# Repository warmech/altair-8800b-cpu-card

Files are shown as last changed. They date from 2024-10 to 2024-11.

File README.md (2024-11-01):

# Altair 8800B CPU Card
This is a reproduction of the MITS Altair 8800B CPU card, with some cleanup to trace routing and pad placement. While there are reproductions of the 8800's CPU card available, the 8800B's CPU card has not (to date) been reproduced. You may be wondering why this version of the Altair's CPU card exists and the original 8800 card is not useable; this is because the architecture of the 8800 and 8800B differ ever so slightly, making each computer's CPU card incompatible with the other without making some hardware changes.

This version of the card incorporates all of the pertinent hardware design of the original 8800B card, but leaves out all of the unnecessary and/or ancillary traces and pads that were placed for potential future development. Orphaned pads, jumpers, and vias have been removed and only two unlabeled jumpers remain in the vicinity of IC "T" near the bottom-left side of the PCB. The goal of this project was not to recreate the card in a 1:1 fashion, as the original PCB was replete with elements that served no discernably meaningful purpose. Instead, this revision offers a nice, clean, annotated PCB for those whose 8800Bs are either missing a CPU card (as mine was) or whose CPU cards are damaged beyond repair.

This design is presently untested and I am awaiting a set to be fabricated. Once I have tested this card in my 8800B, I will update this disclaimer to indicate as much.

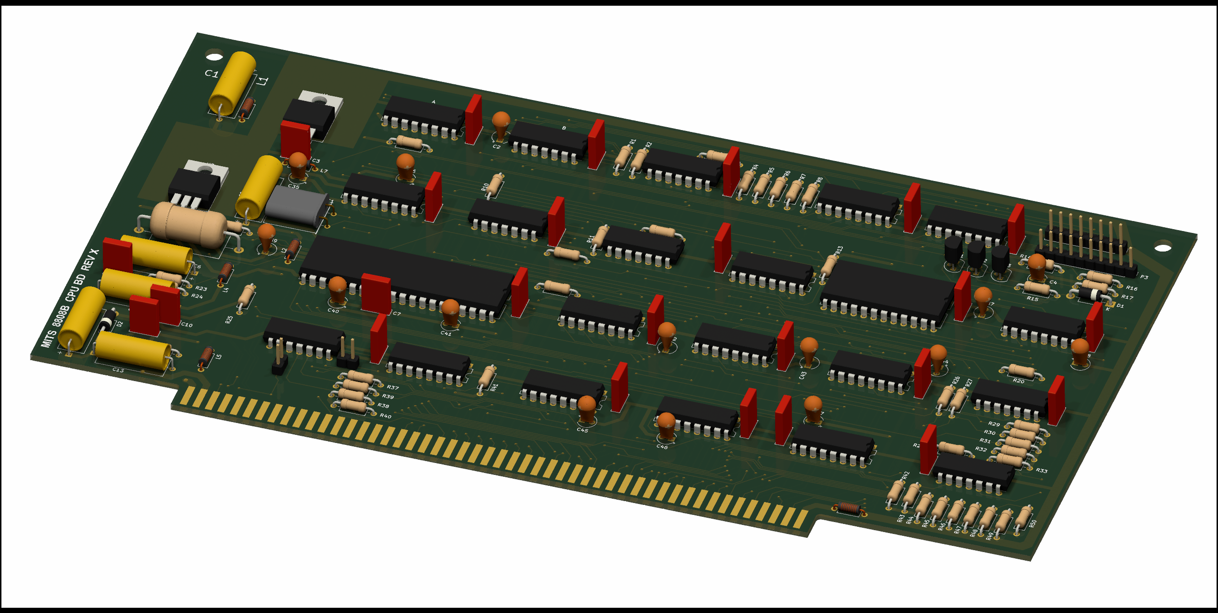
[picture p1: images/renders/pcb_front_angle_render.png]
Altair 8800B CPU Front


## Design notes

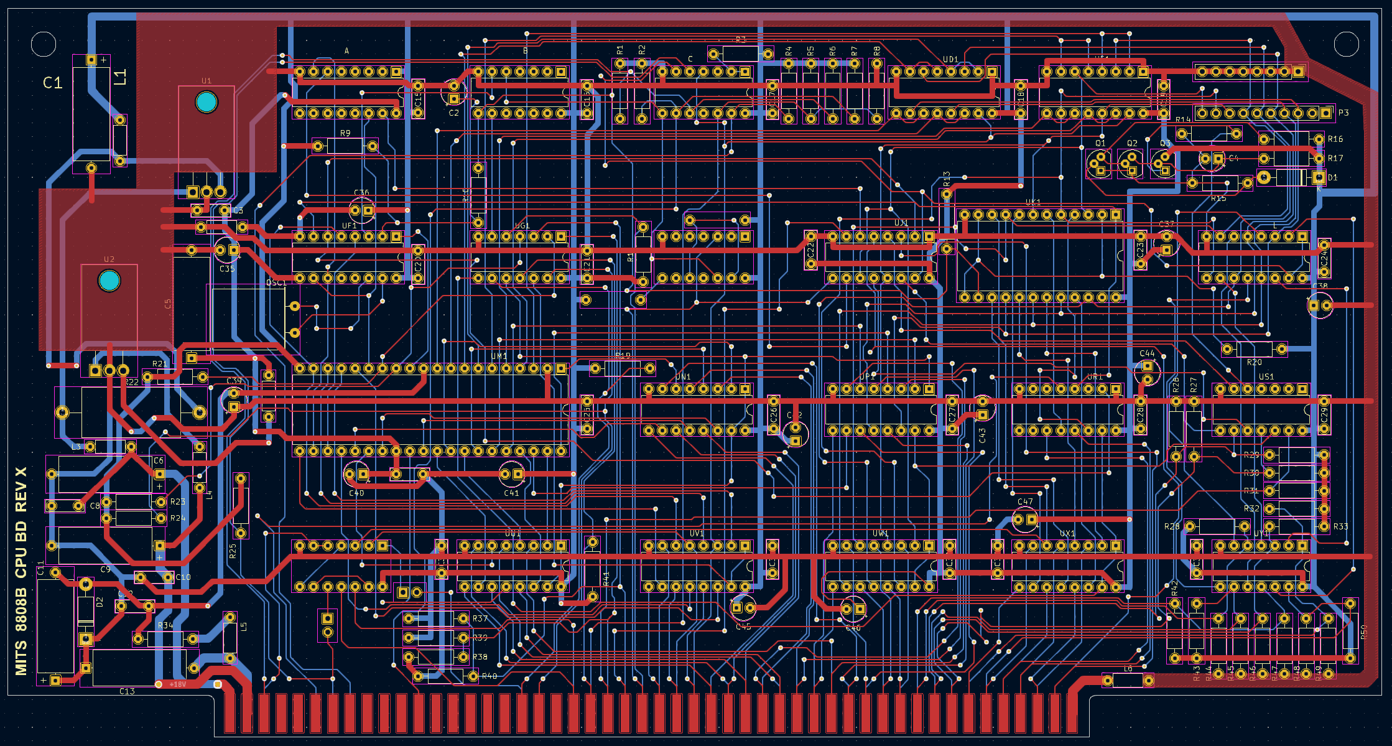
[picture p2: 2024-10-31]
images/renders/pcb_cad_view.png

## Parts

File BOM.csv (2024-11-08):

Source: | C:\Users\wtooker\GitHub\altair-8800b-cpu-card\cad\altair-8800b-cpu-card.kicad_sch
Date: | 11/8/2024 1:40:58 PM
Tool: | Eeschema 7.0.8
Generator: | C:\Program Files\KiCad\7.0\bin\scripting\plugins/bom_csv_grouped_by_value.py
Component Count: | 136
Collated Components:
Item | Qty | Reference(s) | Value | LibPart | Footprint | Datasheet | DNP
1 | 4 | C1, C5, C6, C11 | 33uF 16V | Device:C_Polarized_US | Capacitor_THT_Custom:C_Axial_L17.0mm_D6.5mm_P20.00mm_Horizontal | ~
2 | 1 | C2 | 22uF 16V | Device:C_Polarized_US | Capacitor_THT:CP_Radial_Tantal_D4.5mm_P2.50mm | ~
3 | 3 | C3, C7, C10 | 0.1uF 50V | Device:C | Capacitor_THT:C_Rect_L7.0mm_W2.0mm_P5.00mm | ~
4 | 1 | C4 | 10uF 16V | Device:C_Polarized_US | Capacitor_THT:CP_Radial_Tantal_D4.5mm_P2.50mm | ~
5 | 22 | C8, C12, C15, C16, C17, C18, C19, C20, C21, C22, C23, C24, C25, C26, C27, C28, C29, C30, C31, C32, C33, C34 | 0.1uF 16V | Device:C | Capacitor_THT:C_Rect_L7.0mm_W2.0mm_P5.00mm | ~
6 | 2 | C9, C13 | 10uF 25V | Device:C_Polarized_US | Capacitor_THT_Custom:C_Axial_L17.0mm_D6.5mm_P20.00mm_Horizontal | ~
7 | 13 | C35, C36, C37, C38, C39, C40, C41, C42, C43, C44, C45, C46, C47 | 1uF 35V | Device:C_Polarized_US | Capacitor_THT:CP_Radial_Tantal_D4.5mm_P2.50mm | ~
8 | 1 | D1 | 1N4730 | Diode:1N47xxA | Diode_THT:D_DO-41_SOD81_P10.16mm_Horizontal | https://www.vishay.com/docs/85816/1n4728a.pdf
9 | 1 | D2 | 1N4733 | Diode:1N47xxA | Diode_THT:D_DO-41_SOD81_P10.16mm_Horizontal | https://www.vishay.com/docs/85816/1n4728a.pdf
10 | 1 | J1 | Altair System Bus (S-100) | Connector_Custom:MITS_Altair_Bus_CardEdge | Connector_Custom:Altair_8800_Bus_Card_Edge
11 | 1 | J2 | Interface Pull-Down | Connector_Generic:Conn_01x08 | Connector_PinHeader_2.54mm:PinHeader_1x08_P2.54mm_Vertical | ~
12 | 2 | JP1, JP2 | Unknown Jumper | Jumper:Jumper_2_Open | Connector_PinHeader_2.54mm:PinHeader_1x02_P2.54mm_Vertical | ~
13 | 7 | L1, L2, L3, L4, L5, L6, L7 | Ferrite Bead | Device:L | Inductor_THT:L_Axial_L5.3mm_D2.2mm_P7.62mm_Horizontal_Vishay_IM-1 | ~
14 | 1 | OSC1 | Crystal | Device:Crystal | Crystal:Crystal_HC49-U_Horizontal | ~
15 | 1 | P3 | Interface | Connector_Generic:Conn_01x10 | Connector_PinHeader_2.54mm:PinHeader_1x10_P2.54mm_Vertical | ~
16 | 3 | Q1, Q2, Q3 | 2N4410 | Transistor_Custom:2N4410 | Package_TO_SOT_THT:TO-92
17 | 13 | R1, R2, R8, R26, R27, R37, R39, R44, R45, R46, R47, R48, R49 | 3.3K | Device:R_US | Resistor_THT:R_Axial_DIN0207_L6.3mm_D2.5mm_P10.16mm_Horizontal | ~
18 | 25 | R3, R4, R5, R6, R7, R11, R13, R14, R19, R20, R24, R25, R28, R29, R30, R31, R32, R33, R38, R40, R41, R42, R43, R50, R98 | 2.2K | Device:R_US | Resistor_THT:R_Axial_DIN0207_L6.3mm_D2.5mm_P10.16mm_Horizontal | ~
19 | 1 | R9 | 15K | Device:R_US | Resistor_THT:R_Axial_DIN0207_L6.3mm_D2.5mm_P10.16mm_Horizontal | ~
20 | 1 | R10 | 330 | Device:R_US | Resistor_THT:R_Axial_DIN0207_L6.3mm_D2.5mm_P10.16mm_Horizontal | ~
21 | 1 | R15 | 100 | Device:R_US | Resistor_THT:R_Axial_DIN0207_L6.3mm_D2.5mm_P10.16mm_Horizontal | ~
22 | 2 | R16, R99 | 1K | Device:R_US | Resistor_THT:R_Axial_DIN0207_L6.3mm_D2.5mm_P10.16mm_Horizontal | ~
23 | 1 | R17 | 10K | Device:R_US | Resistor_THT:R_Axial_DIN0207_L6.3mm_D2.5mm_P10.16mm_Horizontal | ~
24 | 2 | R21, R23 | 470 | Device:R_US | Resistor_THT:R_Axial_DIN0207_L6.3mm_D2.5mm_P10.16mm_Horizontal | ~
25 | 1 | R22 | 10 - 2W | Device:R_US | Resistor_THT:R_Axial_DIN0918_L18.0mm_D9.0mm_P25.40mm_Horizontal | ~
26 | 1 | R34 | 620 - 1/2W | Device:R_US | Resistor_THT:R_Axial_DIN0207_L6.3mm_D2.5mm_P10.16mm_Horizontal | ~
27 | 1 | U1 | L7805 | Regulator_Linear:L7805 | Package_TO_SOT_THT:TO-220-3_Horizontal_TabDown | http://www.st.com/content/ccc/resource/technical/document/datasheet/41/4f/b3/b0/12/d4/47/88/CD00000444.pdf/files/CD00000444.pdf/jcr:content/translations/en.CD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
28 | 1 | U2 | L7812 | Regulator_Linear:L7812 | Package_TO_SOT_THT:TO-220-3_Horizontal_TabDown | http://www.st.com/content/ccc/resource/technical/document/datasheet/41/4f/b3/b0/12/d4/47/88/CD00000444.pdf/files/CD00000444.pdf/jcr:content/translations/en.CD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
29 | 1 | UA1 | 4009 | 4xxx:4009 | Package_DIP:DIP-16_W7.62mm | http://www.sycelectronica.com.ar/semiconductores/CD4009.pdf
30 | 2 | UB1, UG1 | 74LS04 | 74xx:74LS04 | Package_DIP:DIP-14_W7.62mm | http://www.ti.com/lit/gpn/sn74LS04
31 | 1 | UC1 | 74LS13 | 74xx:74LS13 | Package_DIP:DIP-14_W7.62mm | http://www.ti.com/lit/gpn/sn74LS13
32 | 2 | UD1, UE1 | 8216 | 8xxx_Custom:8216 | Package_DIP:DIP-16_W7.62mm
33 | 1 | UF1 | 8224 | 8xxx_Custom:8224 | Package_DIP:DIP-16_W7.62mm
34 | 1 | UH1 | 74LS74 | :74LS74_1 | Package_DIP:DIP-14_W7.62mm | 74xx/74hc_hct74.pdf
35 | 2 | UJ1, UL1 | 74LS368 | 74xx:74LS368 | Package_DIP:DIP-16_W7.62mm | http://www.ti.com/lit/gpn/sn74LS368
36 | 1 | UK1 | 8212 | 8xxx_Custom:8212 | Package_DIP:DIP-24_W15.24mm
37 | 1 | UM1 | 8080A | MCU_Intel:8080A | Package_DIP:DIP-40_W15.24mm | http://datasheets.chipdb.org/Intel/MCS-80/intel-8080.pdf
38 | 7 | UN1, UP1, UR1, UU1, UV1, UW1, UX1 | 74LS367 | 74xx:74LS367 | Package_DIP:DIP-16_W7.62mm | http://www.ti.com/lit/gpn/sn74LS367
39 | 2 | US1, UY1 | 74LS14 | 74xx:74LS14 | Package_DIP:DIP-14_W7.62mm | http://www.ti.com/lit/gpn/sn74LS14
40 | 1 | UT1 | 7402 | 74xx:7402 | Package_DIP:DIP-14_W7.62mm | http://www.ti.com/lit/gpn/sn7402

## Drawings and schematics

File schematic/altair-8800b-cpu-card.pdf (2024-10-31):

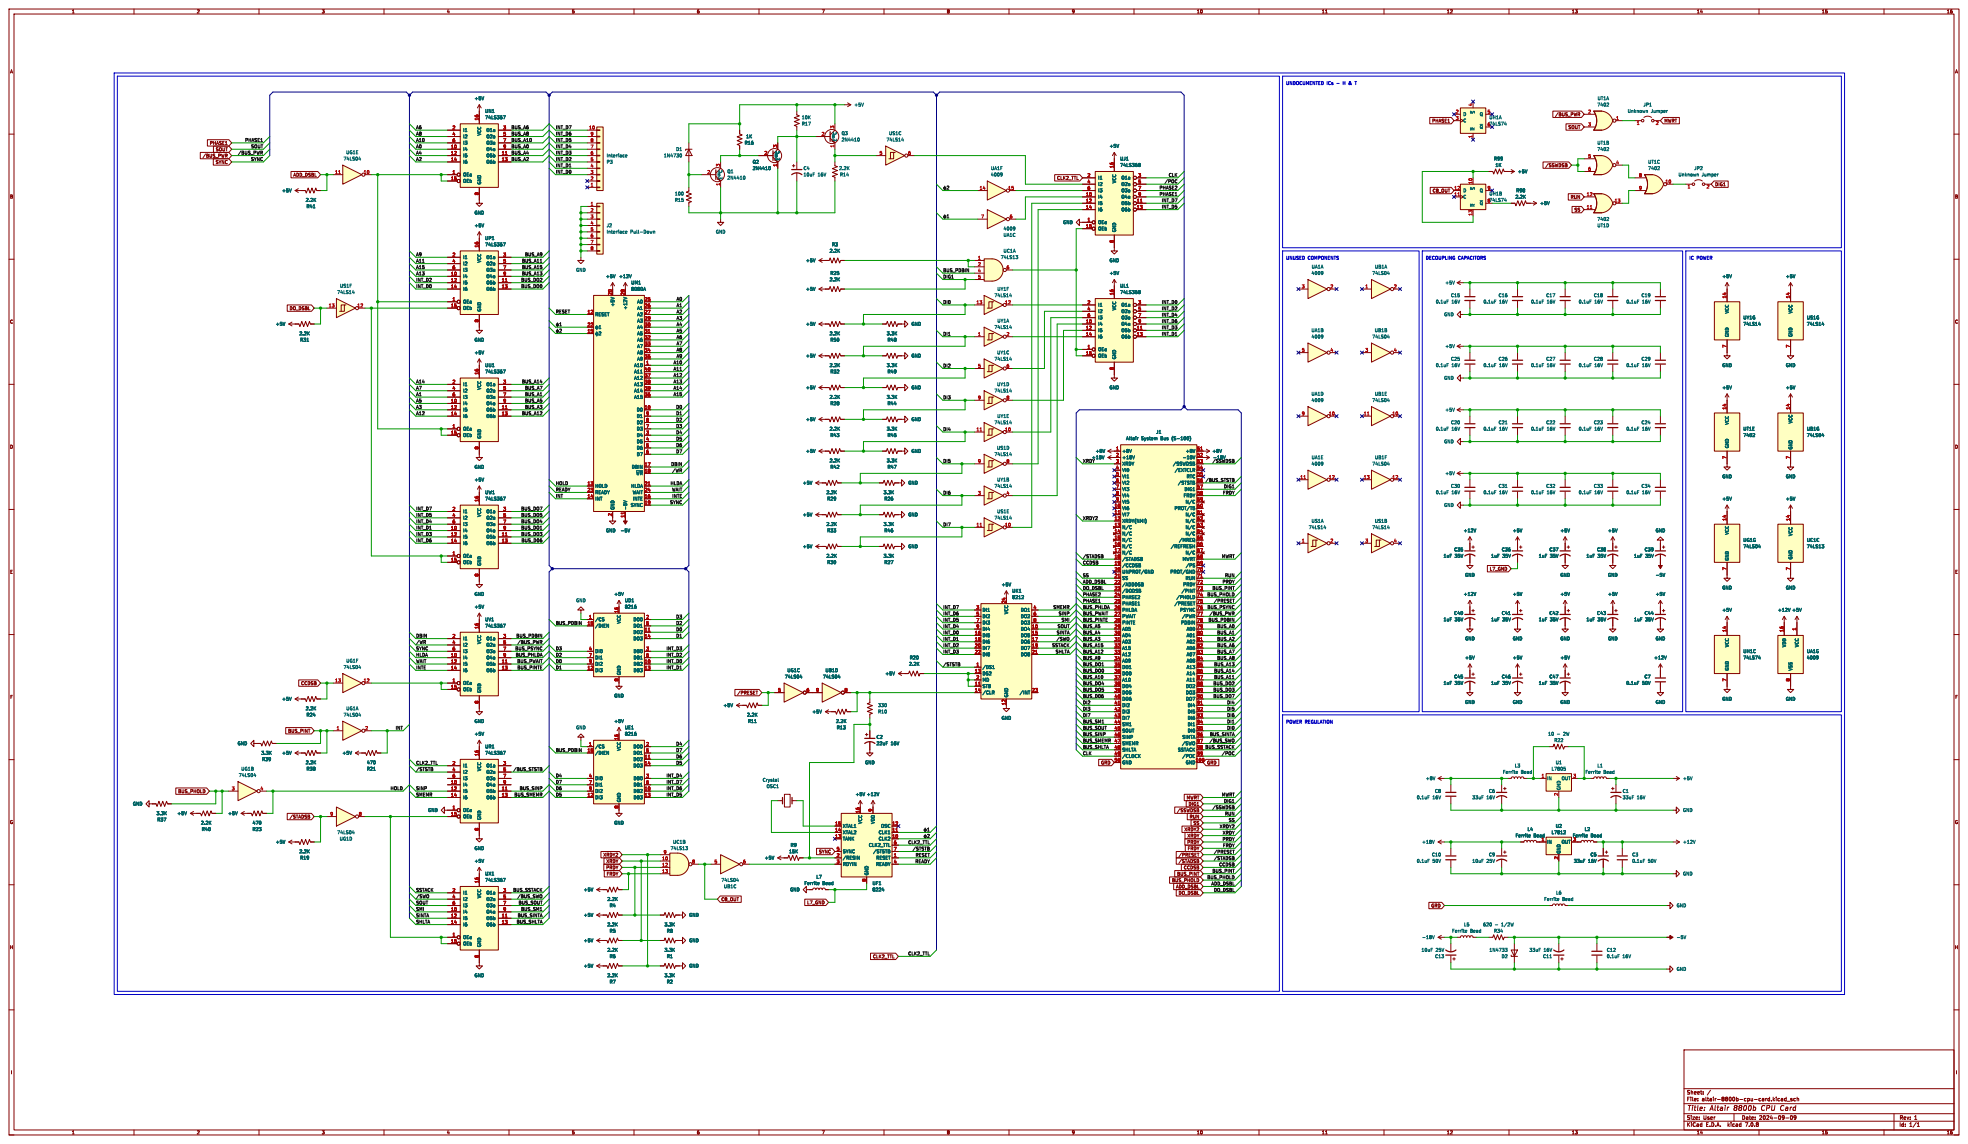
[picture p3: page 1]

Id: 1/1 Title: Altair 8800b CPU Card

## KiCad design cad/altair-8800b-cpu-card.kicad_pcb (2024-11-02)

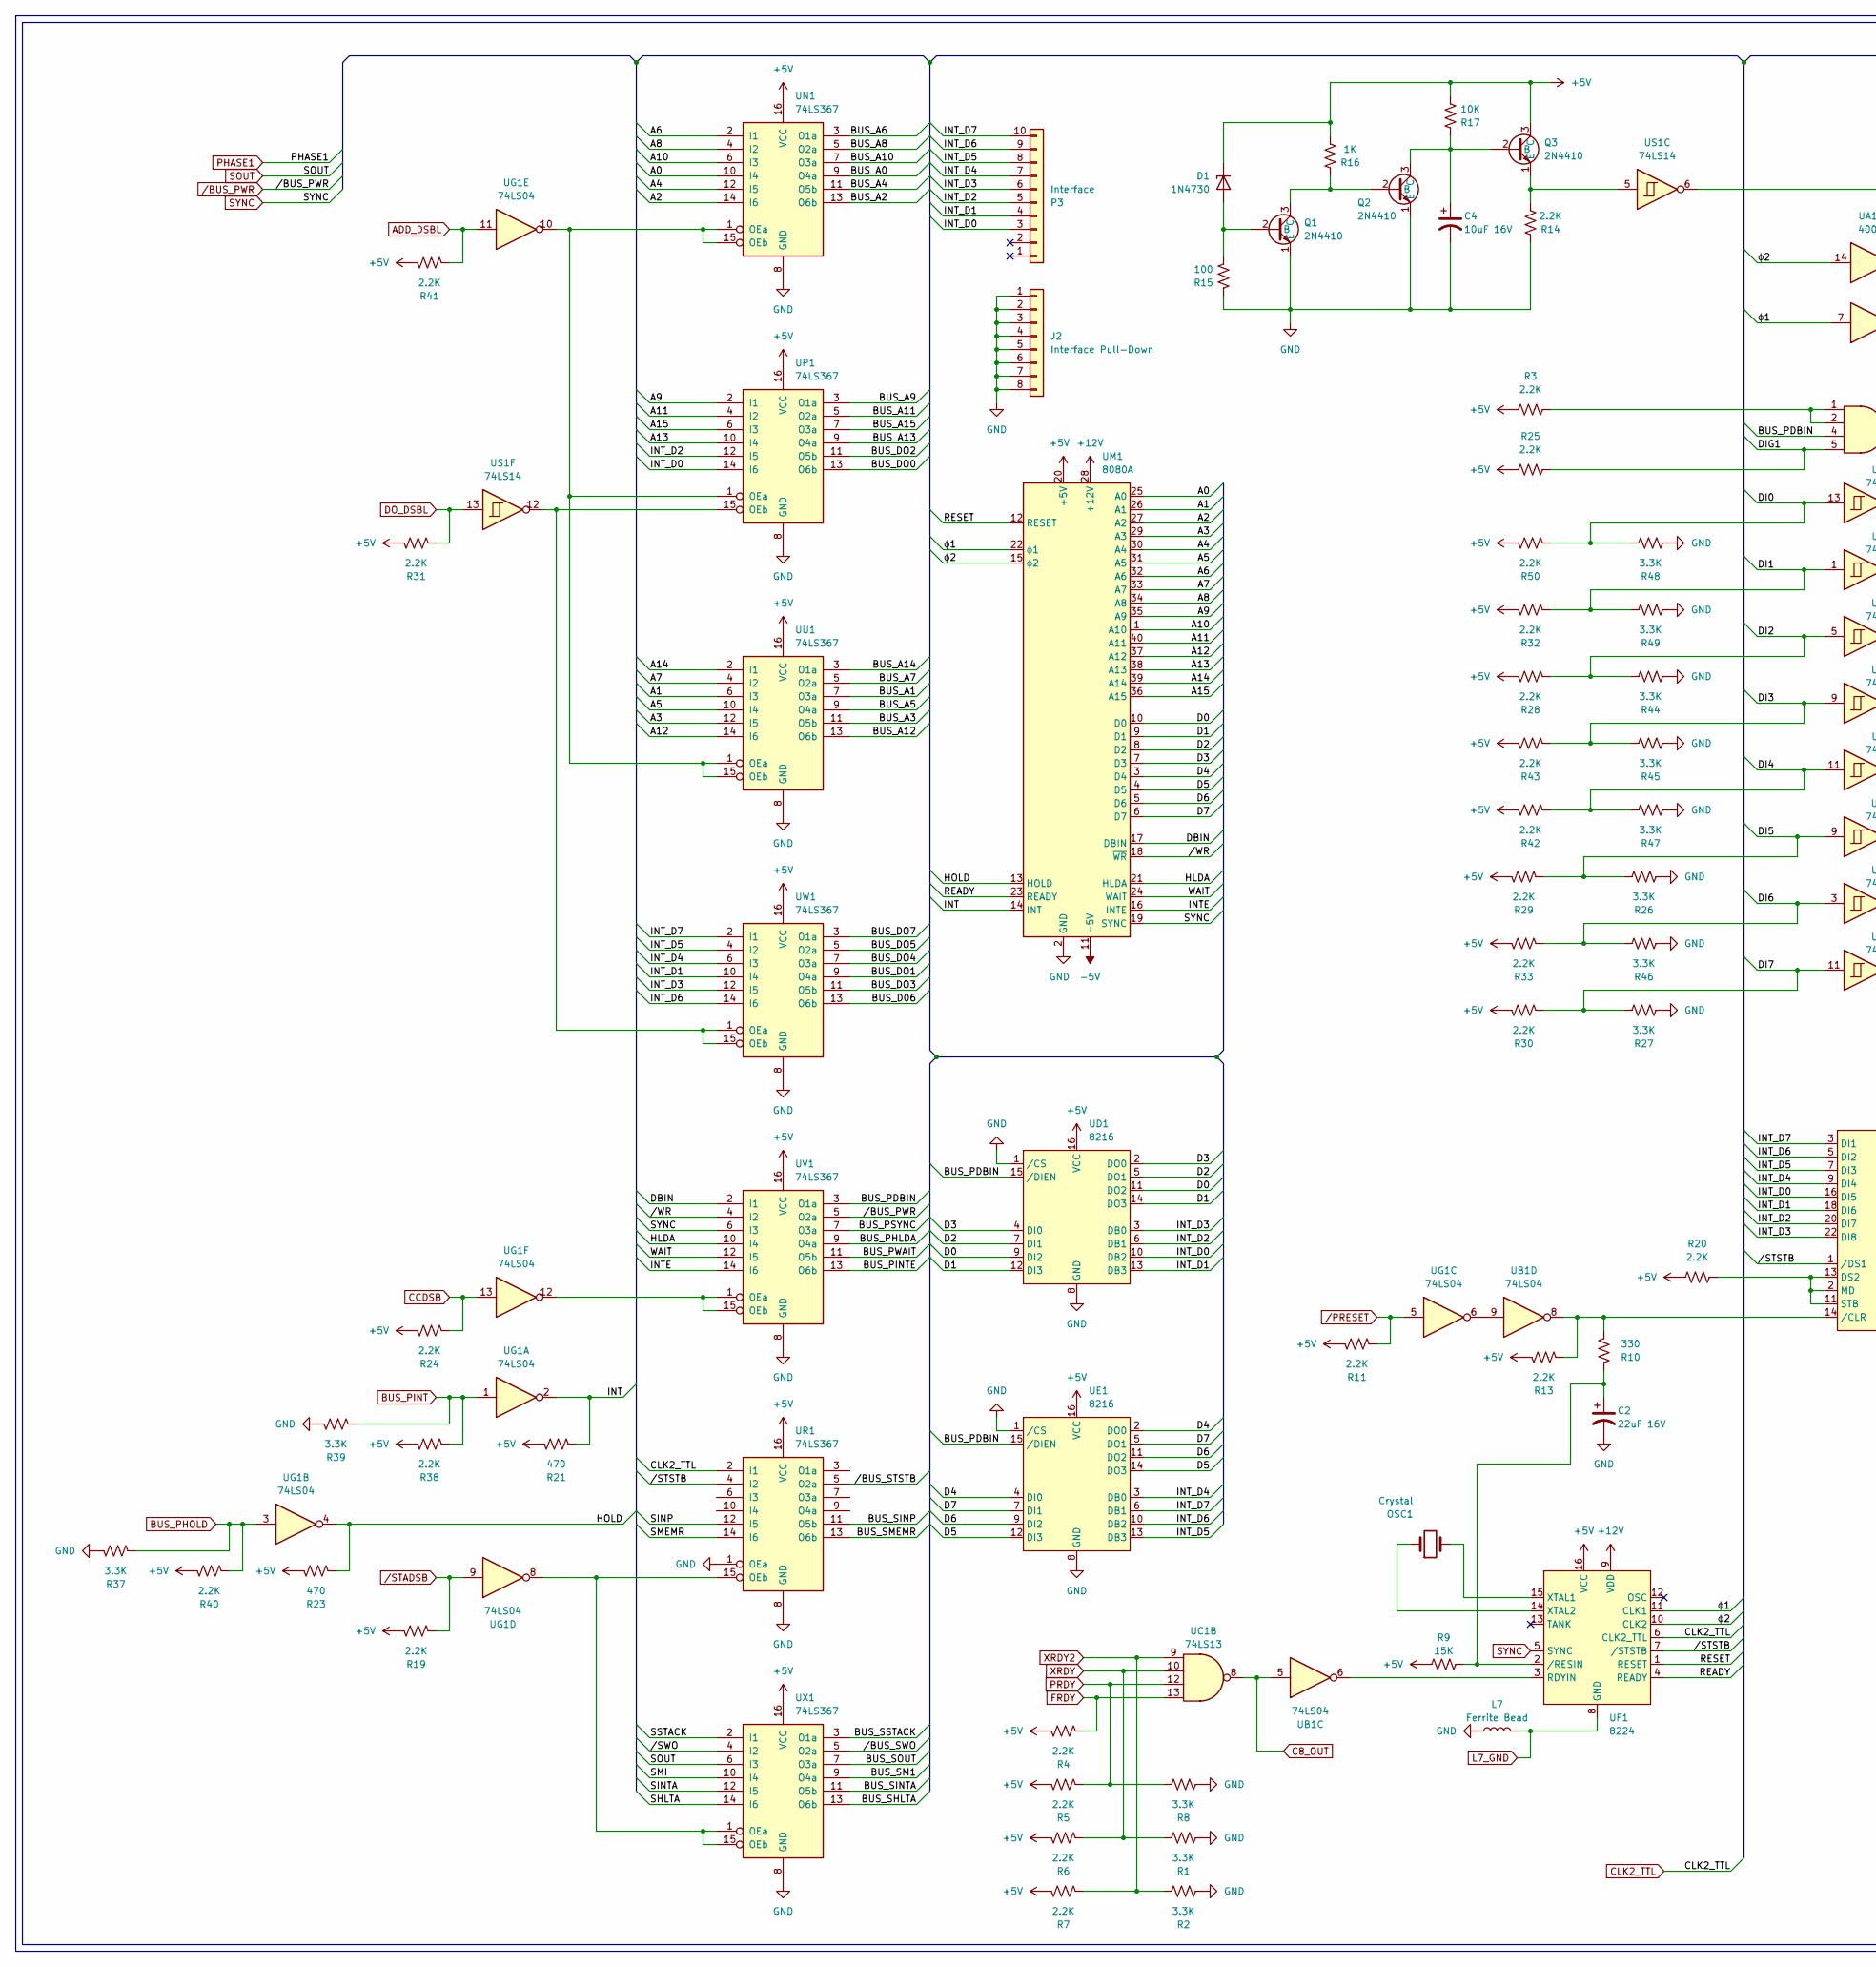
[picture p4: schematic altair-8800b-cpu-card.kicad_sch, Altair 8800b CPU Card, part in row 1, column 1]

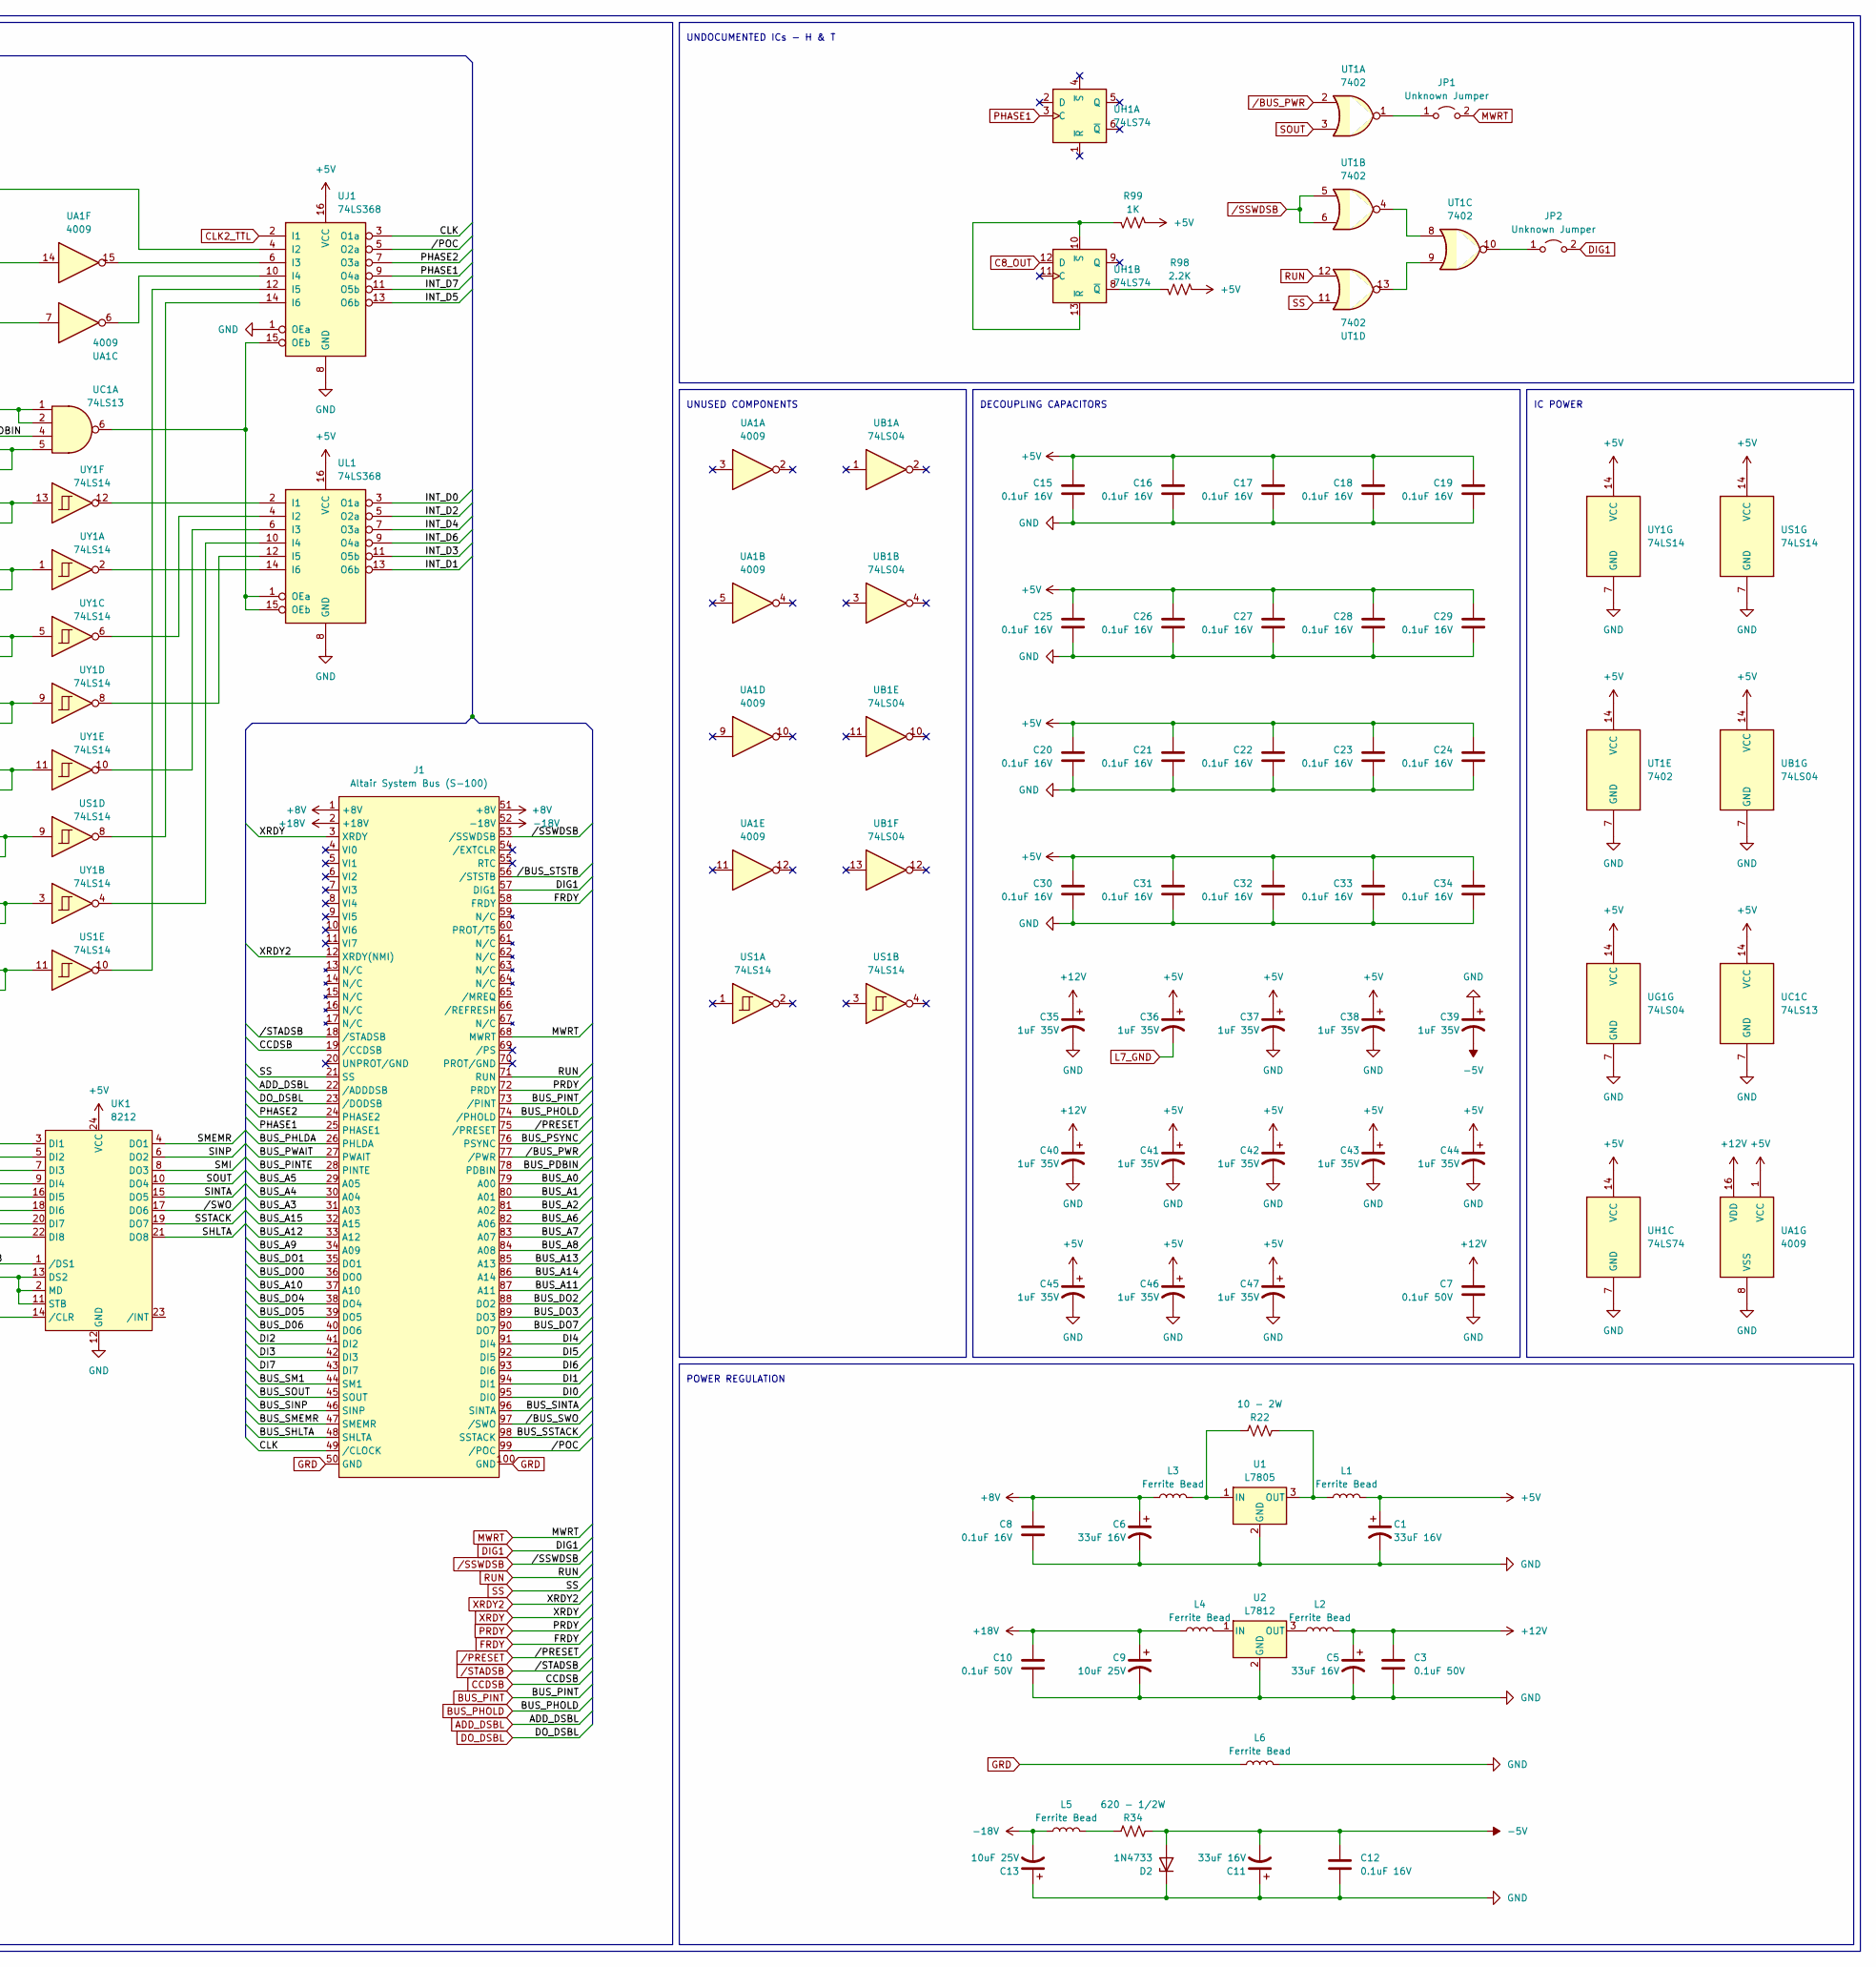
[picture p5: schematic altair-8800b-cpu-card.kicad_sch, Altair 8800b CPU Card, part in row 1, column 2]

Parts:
C1, C5, C6, C11: 33uF 16V; C_Axial_L17.0mm_D6.5mm_P20.00mm_Horizontal
C2: 22uF 16V; CP_Radial_Tantal_D4.5mm_P2.50mm
C3, C7, C10: 0.1uF 50V; C_Rect_L7.0mm_W2.0mm_P5.00mm
C4: 10uF 16V; CP_Radial_Tantal_D4.5mm_P2.50mm
C8, C12, C15, C16, C17, C18, C19, C20, C21, C22, C23, C24, C25, C26, C27, C28, C29, C30, C31, C32, C33, C34: 0.1uF 16V; C_Rect_L7.0mm_W2.0mm_P5.00mm
C9, C13: 10uF 25V; C_Axial_L17.0mm_D6.5mm_P20.00mm_Horizontal
C35, C36, C37, C38, C39, C40, C41, C42, C43, C44, C45, C46, C47: 1uF 35V; CP_Radial_Tantal_D4.5mm_P2.50mm
D1: 1N4730; D_DO-41_SOD81_P10.16mm_Horizontal
D2: 1N4733; D_DO-41_SOD81_P10.16mm_Horizontal
J1: Altair System Bus (S-100); Altair_8800_Bus_Card_Edge
J2: Interface Pull-Down; PinHeader_1x08_P2.54mm_Vertical
JP1, JP2: Unknown Jumper; PinHeader_1x02_P2.54mm_Vertical
L1, L2, L3, L4, L5, L6, L7: Ferrite Bead; L_Axial_L5.3mm_D2.2mm_P7.62mm_Horizontal_Vishay_IM-1
OSC1: Crystal; Crystal_HC49-U_Horizontal
P3: Interface; PinHeader_1x10_P2.54mm_Vertical
Q1, Q2, Q3: 2N4410; TO-92
R1, R2, R8, R26, R27, R37, R39, R44, R45, R46, R47, R48, R49: 3.3K; R_Axial_DIN0207_L6.3mm_D2.5mm_P10.16mm_Horizontal
R3, R4, R5, R6, R7, R11, R13, R14, R19, R20, R24, R25, R28, R29, R30, R31, R32, R33, R38, R40, R41, R42, R43, R50, R98: 2.2K; R_Axial_DIN0207_L6.3mm_D2.5mm_P10.16mm_Horizontal
R9: 15K; R_Axial_DIN0207_L6.3mm_D2.5mm_P10.16mm_Horizontal
R10: 330; R_Axial_DIN0207_L6.3mm_D2.5mm_P10.16mm_Horizontal
R15: 100; R_Axial_DIN0207_L6.3mm_D2.5mm_P10.16mm_Horizontal
R16, R99: 1K; R_Axial_DIN0207_L6.3mm_D2.5mm_P10.16mm_Horizontal
R17: 10K; R_Axial_DIN0207_L6.3mm_D2.5mm_P10.16mm_Horizontal
R21, R23: 470; R_Axial_DIN0207_L6.3mm_D2.5mm_P10.16mm_Horizontal
R22: 10 - 2W; R_Axial_DIN0918_L18.0mm_D9.0mm_P25.40mm_Horizontal
R34: 620 - 1/2W; R_Axial_DIN0207_L6.3mm_D2.5mm_P10.16mm_Horizontal
U1: L7805; TO-220-3_Horizontal_TabDown
U2: L7812; TO-220-3_Horizontal_TabDown
UA1: 4009; DIP-16_W7.62mm
UB1: 74LS04; DIP-14_W7.62mm
UC1: 74LS13; DIP-14_W7.62mm
UD1: 8216; DIP-16_W7.62mm
UE1: 8216; DIP-16_W7.62mm
UF1: 8224; DIP-16_W7.62mm
UG1: 74LS04; DIP-14_W7.62mm
UH1: 74LS74; DIP-14_W7.62mm
UJ1: 74LS368; DIP-16_W7.62mm
UK1: 8212; DIP-24_W15.24mm
UL1: 74LS368; DIP-16_W7.62mm
UM1: 8080A; DIP-40_W15.24mm
UN1: 74LS367; DIP-16_W7.62mm
UP1: 74LS367; DIP-16_W7.62mm
UR1: 74LS367; DIP-16_W7.62mm
US1: 74LS14; DIP-14_W7.62mm
UT1: 7402; DIP-14_W7.62mm
UU1: 74LS367; DIP-16_W7.62mm
UV1: 74LS367; DIP-16_W7.62mm
UW1: 74LS367; DIP-16_W7.62mm
UX1: 74LS367; DIP-16_W7.62mm
UY1: 74LS14; DIP-14_W7.62mm

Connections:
+5V: C1.1, C15.1, C16.1, C17.1, C18.1, C19.1, C20.1, C21.1, C22.1, C23.1, C24.1, C25.1, C26.1, C27.1, C28.1, C29.1, C30.1, C31.1, C32.1, C33.1, C34.1, C36.1, C37.1, C38.1, C41.1, C42.1, C43.1, C44.1, C45.1, C46.1, C47.1, D1.1 (K), L1.2, Q3.3 (C), R3.1, R4.1, R5.1, R6.1, R7.1, R9.1, R11.1, R13.1, R16.1, R17.1, R19.1, R20.1, R21.1, R23.1, R24.1, R25.1, R28.1, R29.1, R30.1, R31.1, R32.1, R33.1, R38.1, R40.1, R41.1, R42.1, R43.1, R50.1, R98.1, R99.1, UA1.1 (VCC), UB1.14 (VCC), UC1.14 (VCC), UD1.16 (VCC), UE1.16 (VCC), UF1.16 (VCC), UG1.14 (VCC), UH1.14 (VCC), UJ1.16 (VCC), UK1.24 (VCC), UL1.16 (VCC), UM1.20 (+5V), UN1.16 (VCC), UP1.16 (VCC), UR1.16 (VCC), US1.14 (VCC), UT1.14 (VCC), UU1.16 (VCC), UV1.16 (VCC), UW1.16 (VCC), UX1.16 (VCC), UY1.14 (VCC)
+8V: C6.1, C8.1, J1.1 (+8V), J1.51 (+8V), L3.1
+12V: C3.1, C5.1, C7.1, C35.1, C40.1, L2.2, UA1.16 (VDD), UF1.9 (VDD), UM1.28 (+12V)
+18V: C9.1, C10.1, J1.2 (+18V), L4.1
-5V: C11.2, C12.1, C39.2, D2.2 (A), R34.2, UM1.11 (-5V)
-18V: C13.2, J1.52 (-18V), L5.1
/A0: UM1.25 (A0), UN1.10 (I4)
/A1: UM1.26 (A1), UU1.6 (I3)
/A2: UM1.27 (A2), UN1.14 (I6)
/A3: UM1.29 (A3), UU1.12 (I5)
/A4: UM1.30 (A4), UN1.12 (I5)
/A5: UM1.31 (A5), UU1.10 (I4)
/A6: UM1.32 (A6), UN1.2 (I1)
/A7: UM1.33 (A7), UU1.4 (I2)
/A8: UM1.34 (A8), UN1.4 (I2)
/A9: UM1.35 (A9), UP1.2 (I1)
/A10: UM1.1 (A10), UN1.6 (I3)
/A11: UM1.40 (A11), UP1.4 (I2)
/A12: UM1.37 (A12), UU1.14 (I6)
/A13: UM1.38 (A13), UP1.10 (I4)
/A14: UM1.39 (A14), UU1.2 (I1)
/A15: UM1.36 (A15), UP1.6 (I3)
/BUS_A0: J1.79 (A00), UN1.9 (O4a)
/BUS_A1: J1.80 (A01), UU1.7 (O3a)
/BUS_A2: J1.81 (A02), UN1.13 (O6b)
/BUS_A3: J1.31 (A03), UU1.11 (O5b)
/BUS_A4: J1.30 (A04), UN1.11 (O5b)
/BUS_A5: J1.29 (A05), UU1.9 (O4a)
/BUS_A6: J1.82 (A06), UN1.3 (O1a)
/BUS_A7: J1.83 (A07), UU1.5 (O2a)
/BUS_A8: J1.84 (A08), UN1.5 (O2a)
/BUS_A9: J1.34 (A09), UP1.3 (O1a)
/BUS_A10: J1.37 (A10), UN1.7 (O3a)
/BUS_A11: J1.87 (A11), UP1.5 (O2a)
/BUS_A12: J1.33 (A12), UU1.13 (O6b)
/BUS_A13: J1.85 (A13), UP1.9 (O4a)
/BUS_A14: J1.86 (A14), UU1.3 (O1a)
/BUS_A15: J1.32 (A15), UP1.7 (O3a)
/BUS_D06: J1.40 (DO6), UW1.13 (O6b)
/BUS_DO0: J1.36 (DO0), UP1.13 (O6b)
/BUS_DO1: J1.35 (DO1), UW1.9 (O4a)
/BUS_DO2: J1.88 (DO2), UP1.11 (O5b)
/BUS_DO3: J1.89 (DO3), UW1.11 (O5b)
/BUS_DO4: J1.38 (DO4), UW1.7 (O3a)
/BUS_DO5: J1.39 (DO5), UW1.5 (O2a)
/BUS_DO7: J1.90 (DO7), UW1.3 (O1a)
/BUS_PDBIN: J1.78 (PDBIN), UC1.4, UD1.15 (/DIEN), UE1.15 (/DIEN), UV1.3 (O1a)
/BUS_PHLDA: J1.26 (PHLDA), UV1.9 (O4a)
/BUS_PINTE: J1.28 (PINTE), UV1.13 (O6b)
/BUS_PSYNC: J1.76 (PSYNC), UV1.7 (O3a)
/BUS_PWAIT: J1.27 (PWAIT), UV1.11 (O5b)
/BUS_SHLTA: J1.48 (SHLTA), UX1.13 (O6b)
/BUS_SINP: J1.46 (SINP), UR1.11 (O5b)
/BUS_SINTA: J1.96 (SINTA), UX1.11 (O5b)
/BUS_SM1: J1.44 (SM1), UX1.9 (O4a)
/BUS_SMEMR: J1.47 (SMEMR), UR1.13 (O6b)
/BUS_SOUT: J1.45 (SOUT), UX1.7 (O3a)
/BUS_SSTACK: J1.98 (SSTACK), UX1.3 (O1a)
/CLK: J1.49 (/CLOCK), UJ1.3 (O1a)
/D0: UD1.9 (DI2), UD1.11 (DO2), UM1.10 (D0)
/D1: UD1.12 (DI3), UD1.14 (DO3), UM1.9 (D1)
/D2: UD1.5 (DO1), UD1.7 (DI1), UM1.8 (D2)
/D3: UD1.2 (DO0), UD1.4 (DI0), UM1.7 (D3)
/D4: UE1.2 (DO0), UE1.4 (DI0), UM1.3 (D4)
/D5: UE1.12 (DI3), UE1.14 (DO3), UM1.4 (D5)
/D6: UE1.9 (DI2), UE1.11 (DO2), UM1.5 (D6)
/D7: UE1.5 (DO1), UE1.7 (DI1), UM1.6 (D7)
/DBIN: UM1.17 (DBIN), UV1.2 (I1)
/DI0: J1.95 (DI0), R48.2, R50.2, UY1.13
/DI1: J1.94 (DI1), R32.2, R49.2, UY1.1
/DI2: J1.41 (DI2), R28.2, R44.2, UY1.5
/DI3: J1.42 (DI3), R43.2, R45.2, UY1.9
/DI4: J1.91 (DI4), R42.2, R47.2, UY1.11
/DI5: J1.92 (DI5), R26.2, R29.2, US1.9
/DI6: J1.93 (DI6), R33.2, R46.2, UY1.3
/DI7: J1.43 (DI7), R27.2, R30.2, US1.11
/HLDA: UM1.21 (HLDA), UV1.10 (I4)
/HOLD: R23.2, UG1.4, UM1.13 (HOLD)
/INT: R21.2, UG1.2, UM1.14 (INT)
/INTE: UM1.16 (INTE), UV1.14 (I6)
/INT_D0: P3.3, UD1.10 (DB2), UK1.16 (DI5), UL1.3 (O1a), UP1.14 (I6)
/INT_D1: P3.4, UD1.13 (DB3), UK1.18 (DI6), UL1.13 (O6b), UW1.10 (I4)
/INT_D2: P3.5, UD1.6 (DB1), UK1.20 (DI7), UL1.5 (O2a), UP1.12 (I5)
/INT_D3: P3.6, UD1.3 (DB0), UK1.22 (DI8), UL1.11 (O5b), UW1.12 (I5)
/INT_D4: P3.7, UE1.3 (DB0), UK1.9 (DI4), UL1.7 (O3a), UW1.6 (I3)
/INT_D5: P3.8, UE1.13 (DB3), UJ1.13 (O6b), UK1.7 (DI3), UW1.4 (I2)
/INT_D6: P3.9, UE1.10 (DB2), UK1.5 (DI2), UL1.9 (O4a), UW1.14 (I6)
/INT_D7: P3.10, UE1.6 (DB1), UJ1.11 (O5b), UK1.3 (DI1), UW1.2 (I1)
/PHASE2: J1.24 (PHASE2), UJ1.7 (O3a)
/READY: UF1.4 (READY), UM1.23 (READY)
/RESET: UF1.1 (RESET), UM1.12 (RESET)
/SHLTA: UK1.21 (DO8), UX1.14 (I6)
/SINP: UK1.6 (DO2), UR1.12 (I5)
/SINTA: UK1.15 (DO5), UX1.12 (I5)
/SMEMR: UK1.4 (DO1), UR1.14 (I6)
/SMI: UK1.8 (DO3), UX1.10 (I4)
/SSTACK: UK1.19 (DO7), UX1.2 (I1)
/WAIT: UM1.24 (WAIT), UV1.12 (I5)
//BUS_STSTB: J1.56 (/STSTB), UR1.5 (O2a)
//BUS_SWO: J1.97 (/SWO), UX1.5 (O2a)
//POC: J1.99 (/POC), UJ1.5 (O2a)
//STSTB: UF1.7 (/STSTB), UK1.1 (/DS1), UR1.4 (I2)
//SWO: UK1.17 (DO6), UX1.4 (I2)
//WR: UM1.18 (~WR), UV1.4 (I2)
/ϕ1: UA1.7, UF1.11 (CLK1), UM1.22 (ϕ1)
/ϕ2: UA1.14, UF1.10 (CLK2), UM1.15 (ϕ2)
ADD_DSBL: J1.22 (/ADDDSB), R41.2, UG1.11
BUS_PHOLD: J1.74 (/PHOLD), R37.2, R40.2, UG1.3
BUS_PINT: J1.73 (/PINT), R38.2, R39.2, UG1.1
C8_OUT: UB1.5, UC1.8, UH1.12 (D)
CCDSB: J1.19 (/CCDSB), R24.2, UG1.13
CLK2_TTL: UF1.6 (CLK2_TTL), UJ1.2 (I1), UR1.2 (I1)
DIG1: J1.57 (DIG1), JP2.2 (B), R25.2, UC1.5
DO_DSBL: J1.23 (/DODSB), R31.2, US1.13
FRDY: J1.58 (FRDY), R4.2, UC1.13
GND: C1.2, C2.2, C3.2, C4.2, C5.2, C6.2, C7.2, C8.2, C9.2, C10.2, C11.1, C12.2, C13.1, C15.2, C16.2, C17.2, C18.2, C19.2, C20.2, C21.2, C22.2, C23.2, C24.2, C25.2, C26.2, C27.2, C28.2, C29.2, C30.2, C31.2, C32.2, C33.2, C34.2, C35.2, C37.2, C38.2, C39.1, C40.2, C41.2, C42.2, C43.2, C44.2, C45.2, C46.2, C47.2, D2.1 (K), J2.1, J2.2, J2.3, J2.4, J2.5, J2.6, J2.7, J2.8, L6.2, L7.1, Q1.1 (E), Q2.1 (E), R1.1, R2.1, R8.1, R14.2, R15.2, R26.1, R27.1, R37.1, R39.1, R44.1, R45.1, R46.1, R47.1, R48.1, R49.1, U1.2 (GND), U2.2 (GND), UA1.8 (VSS), UB1.7 (GND), UC1.7 (GND), UD1.1 (/CS), UD1.8 (GND), UE1.1 (/CS), UE1.8 (GND), UG1.7 (GND), UH1.7 (GND), UJ1.1 (OEa), UJ1.8 (GND), UK1.12 (GND), UL1.8 (GND), UM1.2 (GND), UN1.8 (GND), UP1.8 (GND), UR1.1 (OEa), UR1.8 (GND), US1.7 (GND), UT1.7 (GND), UU1.8 (GND), UV1.8 (GND), UW1.8 (GND), UX1.8 (GND), UY1.7 (GND)
GRD: J1.50 (GND), J1.100 (GND), L6.1
L7_GND: C36.2, L7.2, UF1.8 (GND)
MWRT: J1.68 (MWRT), JP1.2 (B)
unnamed: D1.2 (A), Q1.2 (B), R15.1
unnamed: JP1.1 (A), UT1.1
unnamed: JP2.1 (A), UT1.10
unnamed: L5.2, R34.1
unnamed: Q1.3 (C), Q2.2 (B), R16.2
unnamed: C4.1, Q2.3 (C), Q3.2 (B), R17.2
unnamed: Q3.1 (E), R14.1, US1.5
unnamed: R3.2, UC1.1, UC1.2
unnamed: L3.2, R22.1, U1.1 (IN)
unnamed: L1.1, R22.2, U1.3 (OUT)
unnamed: L4.2, U2.1 (IN)
unnamed: L2.1, U2.3 (OUT)
unnamed: UB1.9, UG1.6
unnamed: UB1.6, UF1.3 (RDYIN)
unnamed: OSC1.2, UF1.15 (XTAL1)
unnamed: OSC1.1, UF1.14 (XTAL2)
unnamed: C2.1, R9.2, R10.1, UF1.2 (/RESIN)
unnamed: R98.2, UH1.8 (~Q)
unnamed: R99.2, UH1.10 (~S), UH1.13 (~R)
unnamed: UJ1.4 (I2), US1.6
unnamed: UA1.15, UJ1.6 (I3)
unnamed: UA1.6, UJ1.10 (I4)
unnamed: UJ1.12 (I5), US1.10
unnamed: UJ1.14 (I6), US1.8
unnamed: UC1.6, UJ1.15 (OEb), UL1.1 (OEa), UL1.15 (OEb)
unnamed: R20.2, UK1.2 (MD), UK1.11 (STB), UK1.13 (DS2)
unnamed: R10.2, R13.2, UB1.8, UK1.14 (/CLR)
unnamed: UL1.2 (I1), UY1.12
unnamed: UL1.4 (I2), UY1.6
unnamed: UL1.6 (I3), UY1.10
unnamed: UL1.10 (I4), UY1.4
unnamed: UL1.12 (I5), UY1.8
unnamed: UL1.14 (I6), UY1.2
unnamed: UG1.10, UN1.1 (OEa), UN1.15 (OEb), UP1.1 (OEa), UU1.1 (OEa), UU1.15 (OEb)
unnamed: UP1.15 (OEb), US1.12, UW1.1 (OEa), UW1.15 (OEb)
unnamed: UG1.8, UR1.15 (OEb), UX1.1 (OEa), UX1.15 (OEb)
unnamed: UT1.4, UT1.8
unnamed: UT1.9, UT1.13
unnamed: UG1.12, UV1.1 (OEa), UV1.15 (OEb)
PHASE1: J1.25 (PHASE1), UH1.3 (C), UJ1.9 (O4a)
PRDY: J1.72 (PRDY), R5.2, R8.2, UC1.12
RUN: J1.71 (RUN), UT1.12
SOUT: UK1.10 (DO4), UT1.3, UX1.6 (I3)
SS: J1.21 (SS), UT1.11
SYNC: UF1.5 (SYNC), UM1.19 (SYNC), UV1.6 (I3)
XRDY: J1.3 (XRDY), R1.2, R6.2, UC1.10
XRDY2: J1.12 (XRDY(NMI)), R2.2, R7.2, UC1.9
/BUS_PWR: J1.77 (/PWR), UT1.2, UV1.5 (O2a)
/PRESET: J1.75 (/PRESET), R11.2, UG1.5
/SSWDSB: J1.53 (/SSWDSB), UT1.5, UT1.6
/STADSB: J1.18 (/STADSB), R19.2, UG1.9

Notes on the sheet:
DECOUPLING CAPACITORS
POWER REGULATION
IC POWER
UNUSED COMPONENTS
UNDOCUMENTED ICs - H & T

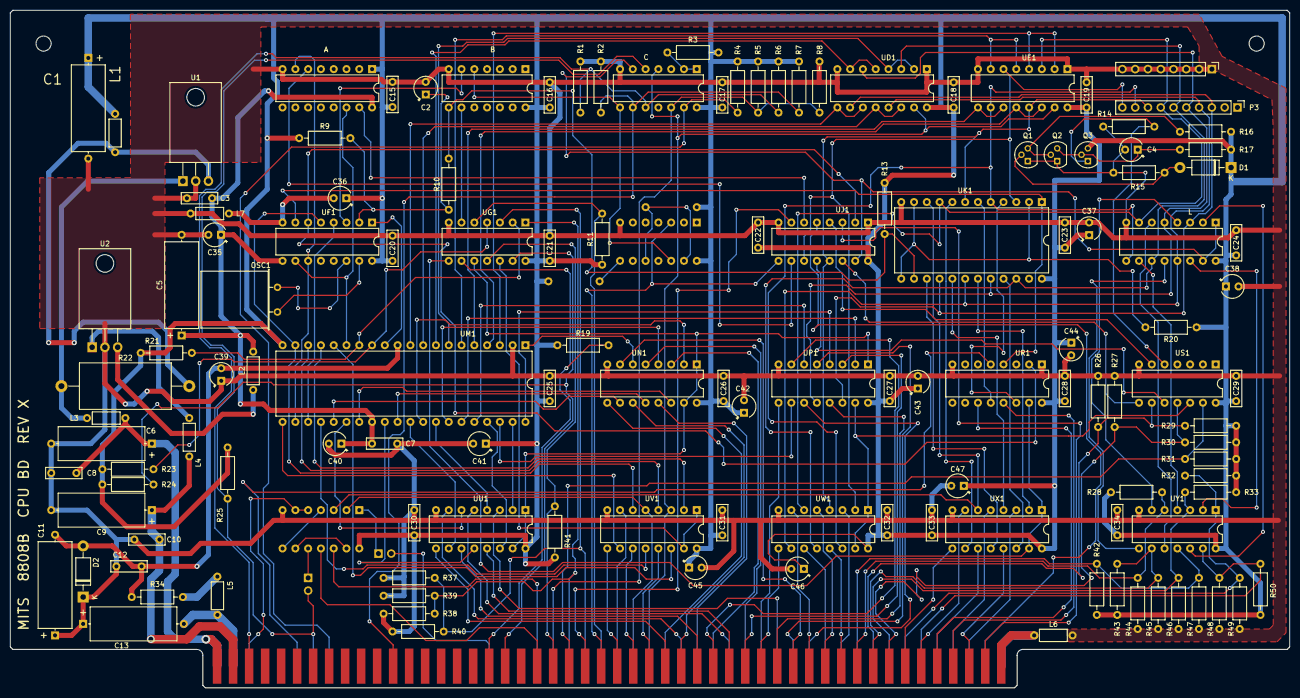
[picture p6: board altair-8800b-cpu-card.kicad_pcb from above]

Board: 2 copper layers, 254.2 x 134.6 mm, 136 parts (0 on the bottom side), 170 nets.

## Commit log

2024-10-31 Initial release
    [altair-8800b-cpu-card.kicad_pcb, altair-8800b-cpu-card.kicad_sch]
2024-11-02 Added miters to PCB corners
    [altair-8800b-cpu-card.kicad_pcb]
2024-11-08 Generated BOM
    [BOM.csv]
